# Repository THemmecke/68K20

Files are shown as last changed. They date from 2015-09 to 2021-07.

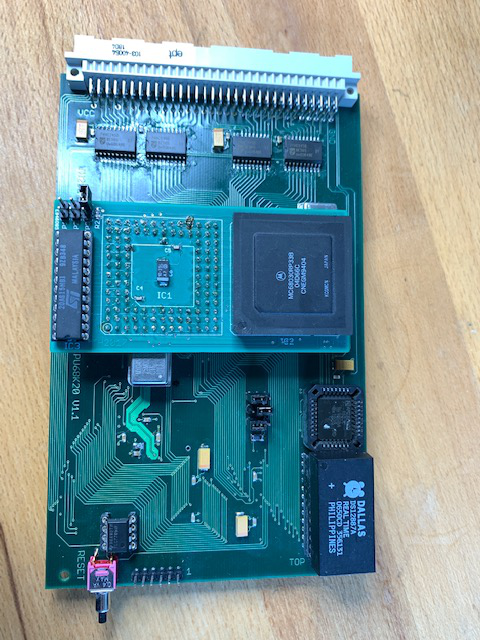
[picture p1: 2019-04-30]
ADAP030/IMG_0259.JPG

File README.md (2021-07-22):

# 68K20
68020 Board EAGLE/VHDL

This repository contains EAGLE and VHDL sources for a 68020 based SBC. The ECB based SBC provides a 68020 cpu, 68881/2 FPU, full 32 bit address and databus, 4MB SRAM and 512KB FLASH on board, 12(C)887 RTC.
It can be used with the GDP-FPGA (https://github.com/THemmecke/GDPFPGAII) to build a complete microcomputer system.

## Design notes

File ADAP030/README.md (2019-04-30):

# 68030 Adapter

With this adapter plugged into the 68020 socket of the CPU68K20 the card upgrades to an CPU68K30 with 

  - 68030/33Mhz CPU (tested)
  - MMU (!)
  - 68882 FPU

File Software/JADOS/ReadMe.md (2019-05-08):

# JADOS 3.50

This directory contains a zipped JADOS image for use with sd cards (GDP-FPGA) and the 680x0 SBCs.

block size: 512 byte
blocks:     133320
size:       68.259.840   Byte (65MB)

Copy to sd card with linux:

1) check with lsblk where your sd card is mounted:

```
$ lsblk 
NAME   MAJ:MIN RM  SIZE RO TYPE MOUNTPOINT
fd0      2:0    1    4K  0 disk 
sda      8:0    0  100G  0 disk 
|-sda1   8:1    0 92.4G  0 part /
|-sda2   8:2    0    1K  0 part 
`-sda5   8:5    0  7.6G  0 part 
sdc      8:32   1 14.1M  0 disk     <---- ()
`-sdc1   8:33   1 13.6M  0 part 
sr0     11:0    1 1024M  0 rom  
```

2) write image:

```
 [sudo] dd bs=512 count=133320 if=jados.img of=/dev/sdc [status=progress]
```

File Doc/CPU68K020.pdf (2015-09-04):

## CPU68K020

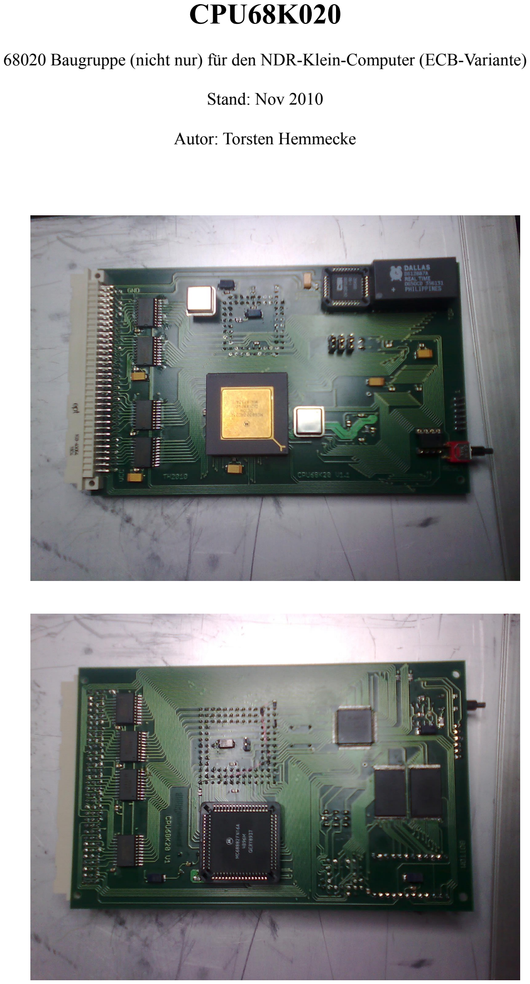
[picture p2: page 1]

68020 Baugruppe (nicht nur) für den NDR-Klein-Computer (ECB-Variante)

Stand: Nov 2010

Autor: Torsten Hemmecke

Wichtiger Hinweis:

Die in dieser Anleitung wiedergegebenen Schaltungen und Verfahren werden ohne Rücksicht auf die Patentlage oder Lizenzrechte Dritter mitgeteilt. Sie sind ausschließlich für private Zwecke und Lehrzwecke bestimmt und dürfen nicht gewerblich genutzt werden. *)
Alle Schaltungen und technische Angaben in dieser Anleitung wurden vom Autor sorgfältig erarbeitet bzw. zusammengestellt. Trotzdem sind Fehler nicht aus zuschließen. Daher kann der Autor weder eine Garantie noch die juristische Verantwortung oder irgend eine Haftung für Folgen, die auf fehlerhafte Angaben zurückgehen, übernehmen. Für die Mitteilung eventueller Fehler ist der Autor jederzeit dankbar.
Die Rechte an Firmennamen, Logos und Warenzeichen, die in dieser Anleitung genannt werden, liegen bei den jeweiligen Inhabern.

*) Bei gewerblicher Nutzung ist vorher die Genehmigung des möglichen Lizenz- oder Rechteinhabers einzuholen.

Inhalt

### 1 Vorwort

Die Baugruppe CPU68k020 entstand im Rahmen des Projektes „NKC Redesign“ das zum Ziel hat, den legendären NDR-Klein-Computer mit heute (Stand 2010) erhältlichen Bauelementen neu aufzubauen und bis hin zum Einsatz mit einem kleinen Linux-Kernel. Das ganze System verwendet einen ECB Bus, wobei die Belegung des Busses zum MC-Computer kompatibel ist und darüber hinaus 16/32bit Erweiterungen vorsieht.
Die CPU68k020 soll volle Software-Kompatibilität zum original NKC bieten.
Auf der Karte sind bis zu 4MB Speicher, ein 8bit-ROM für den BOOT-Loader / GP, eine Echtzeit-UHR (kompatibel zur Uhren-Baugruppe UHR3 von Jens Mewes), die komplette Banken-Logik und ein PLCC Sockel für eine FPU (MC68881/68882) integriert. Es steht ein 32-bit ECB-Bus-Interface zur Verfügung.

Zusammen mit der GDP-FPGA von Andreas Voggeneder steht damit ein vollständiges NKC System zur Verfügung, das bereits JADOS über eine SD-CARD bootet.

### 2 Änderungshistorie

In der vorliegenden Version 1.1.2 sind keine Fehler bekannt.

### 3 Kurzbeschreibung der Funktion

Die Baugruppe CPU68k020 stellt eine vollständige 32Bit CPU für den NKC dar. Sie enthält zusätzlich zur originalen CPU68020 bereits 4MB RAM, die komplette Banken-Logik sowie die UHR3 Baugruppe und ist voll softwarekompatibel zu diesen Baugruppen. Somit kann sämtliche Software des NKC darauf betrieben werden. Die Hardware ist auf einer Europakarte aufgebaut wird mit einen 32-Bit ECB-Bus-Anschluß betrieben werden.

### 4 Technische Daten

Europakarte 160 x 100 mm 4 Lagen (2 Supply Planes) CPU 68020-16/25/33 MHz
FPU 68881/68882
ECB-Bus (32-bit)
Stromaufnahme ca. …. mA
Gerätetyp; Betriebsspannung 5V 4GB adressierbar
4MB RAM OnBoard
512K FLASH OnBoard
RTC 12(C)887

### 5 Prinzipbeschreibung

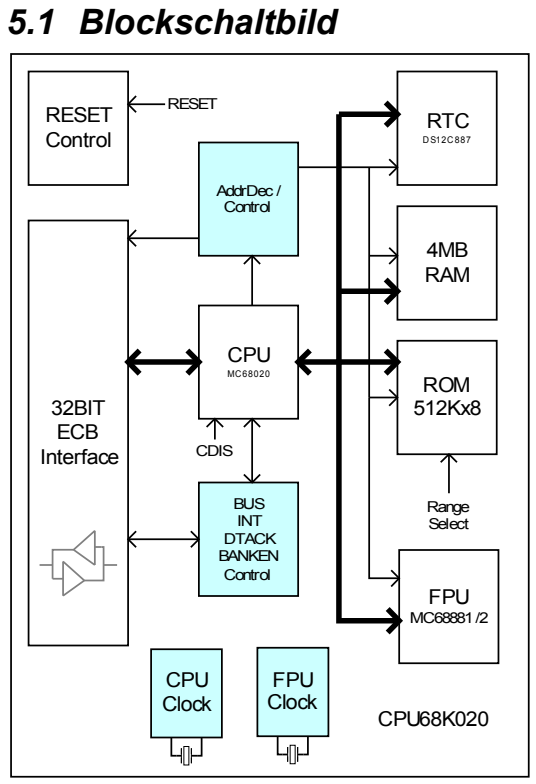
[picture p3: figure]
5.1 Blockschaltbild; AddrDec / Control; CPU Clock; 32BIT ECB Interface; CPU; RESET Control; RTC; 4MB RAM; ROM 512Kx8; BUS INT DTACK BANKEN Control; CPU68K020; FPU MC68881/2; Range Select; CDIS; FPU Clock; RESET

### 5.2 Beschreibung des Blockschaltbildes

Die Baugruppe stellt einen kompletten Signle Board Computer (SBC) mit 16Bit MC68020 CPU dar. Zusammen mit der GDP-FPGA entsteht so ein vollständiger NKC mit 68000 CPU.
Das Design ist dabei völlig offen und nicht auf den Betrieb im NKC beschränkt. Durch Anpassen des CPLDs kann die Funktionalität des SBC nach Belieben angepasst werden.

Es ist bereits eine RTC (Real Time Clock) mit einem DS12(C)887 von Dallas integriert, der im CPLD als UHR3 Baugruppe eingeblendet wird. Eine Funktionsbeschreibung findet sich in der Dokumentation von UHR3 [].

Es können bis zu 4MB RAM (NKC Vollausbau) und xK ROM eingesetzt werden. Die Verwendung der RAM/ROM Bereiche kann über die Konfiguration des CPLDs variiert werden. In der Grundkonfiguration werden 4MB RAM und xKB ROM als BOOT-Loader verwendet.

Die farblich hervorgehobenen Blöcke sind in einem CPLD realisiert.

Die Bus Steuerung sowie DTACK/WAIT Generierung wird im CPLD erledigt. Es können die IRQx, NMI und INT Leitungen des ECB Busses im CPLD beliebig auf die IPL Leitungen der CPU geschaltet werden.

Darüber hinaus kümmert sich das CPLD um die notwendigen Adress-Dekodierungen von IO und MEM Zugriffen (lokal/nicht lokal etc.) und realisiert das BANKEN Register zum Ausblenden des ROM aus dem Adressraum des 68020.

Als Reset Baustein wird ein TLC7725 eingesetzt. Der Baustein sorgt bei Einschalten für einen genügend langen RESET Puls, so dass sich die Versorgungsspannung und die Signale stabilisieren können. Außerdem wird die Versorgungsspannung überwacht und bei Unterschreitung ein Reset ausgelöst um einen undefinierten Zustand des Systems zu vermeiden Außerdem kann ein externer Reset-Taster angeschlossen werden.

Ein Sockel für eine FPU (68881 od. 68882) ist vorhanden und kann wahlweise bestückt werden.

Das 32Bit ECB Bus Interface stellt die Verbindung zu weiteren Karten über den ECB Bus her. So kann mit einer SRAM_24MB der verfügbare Speicher auf 28MB erweitert werden. Damit kann ohne Probleme ein uCLinux System betrieben werden. Der Zugriff auf die externe Speicherkarte (SRAM_24MB) ist mit einem 68020-25MHz getestet und benötigt keine weiteren WAIT-States.

### 5.3 Erweiterung des ECB-BUS auf 32 Bit

Damit der 68020 auch mit voller Bus-Breite auf Peripherie zugreifen kann, wurde der Bus auf 32-Bit erweitert. Er bleibt dabei Kompatibel zum Z80-Bus (siehe Baugruppe SBC4) und zum 16Bit Bus des 68000 (siehe Baugruppe CPU68K).

Reihe | A | B | C
1 | 5V | 5V | 5V
2 | D5 | A20 | D0
3 | D6 | A21 | D7
4 | D3 | A22 | D2
5 | D4 | A23 | A0
6 | A2 | D8 | A3
7 | A4 | D9 | A1
8 | A5 | D10 | A8
9 | A6 | D11 | A7
10 | WAIT\ | D12 | A24
11 | BUSRQ\ | D13 | A25
12 | A18 | D14 | A19
13 | | D15 | BANKEN
14 | A26 | D24 | D1
15 | (020-A0) | D25 | A27
16 | (020-A1) | D26 | A28
17 | A17 | IRQ4 | A11
18 | A14 | IRQ3 | A10
19 | A29 | IRQ2 | A16
20 | M1\ | IRQ1 | NMI\
21 | INT\ | IRQ0
22 | D27 | D16 | WR\
23 | D28 | D17
24 | D29 | D18 | RD\
25 | D30 | D19 | HALT/
26 | D31 | D20
27 | IORQ\ | D21 | A12
28 | | DS0/UDS/SIZ0 | A15
29 | A13 | DS1/LDS/SIZ1 | CLK
30 | A9 | D22 | MREQ\
31 | BUSAK\ | D23 | RESET\
32 | GND | GND | GND
GRÜN | = NKC-ECB-BUS Belegung
ORANGE | = 16Bit Erweiterung (68000)
VIOLETT | = 32Bit Erweiterung (68020 – asynchrones Bus Design)
HBLAU | = evtl. für synchrones Bus-Design (ab 68040) vorgesehen

### 5.4 Das CPLD

Im Folgenden wird im Wesentlichen das CPLD in der NKC Version beschrieben. Prinzipiell kann das Verhalten der CPU-Baugruppe auch an andere Anwendungsfälle angepasst werden, z.B. kann das Interrupthandling verfeinert und die BUS Arbitration für die Verwendung mehrerer CPUs angepasst werden. Auch die dekodierten Adressbereiche sind hier rekonfigurierbar.

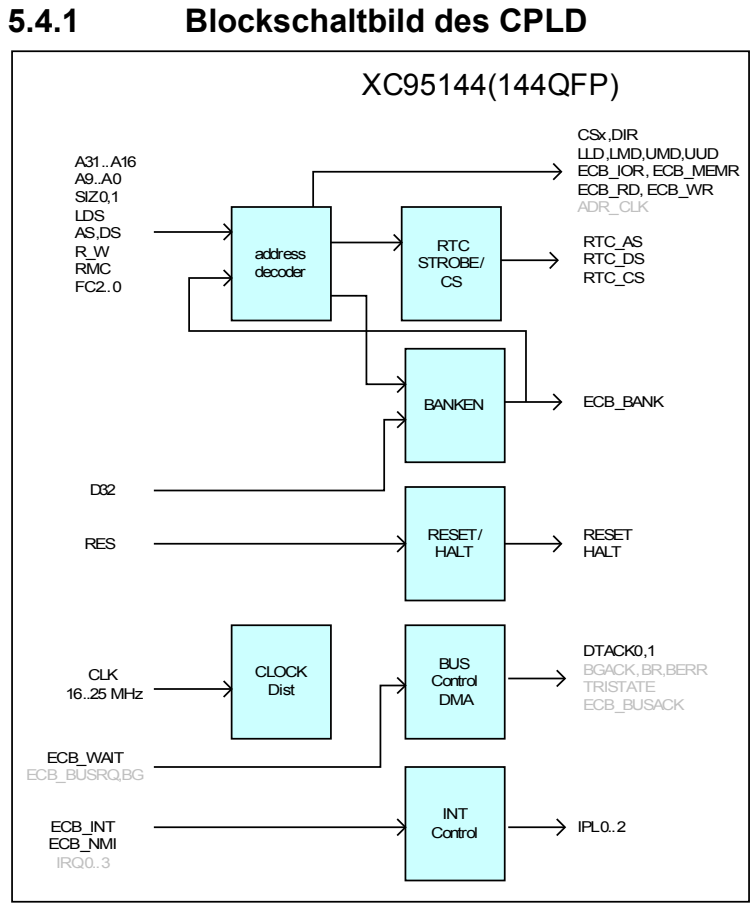
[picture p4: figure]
5.4.1 Blockschaltbild des CPLD; address decoder; RTC STROBE/; A31..A16 A9..A0 SIZ0,1 LDS AS,DS R_W RMC FC2..0; RTC_AS RTC_DS RTC_CS; XC95144(144QFP); CLK 16..25 MHz; BANKEN; ECB_BANK; RESET/ HALT; RESET HALT RES; CSx,DIR LLD,LMD,UMD,UUD ECB_IOR, ECB_MEMR ECB_RD, ECB_WR ADR_CLK; CLOCK Dist; BUS Control DMA; DTACK0,1 BGACK,BR,BERR TRISTATE ECB_BUSACK; INT; Control ECB_INT; IPL0..2; ECB_NMI IRQ0..3; ECB_WAIT ECB_BUSRQ,BG

Signale, die im Standard NKC Design nicht verwendet werden sind ausgegraut.

### 5.4.2 Funktionsbeschreibung des CPLDs

Das VHDL File definiert zunächst die Signale, die der Baustein nach Außen hin zur Verfügung stellt. Danach werden einige Konstanten definiert, die eine Anpassung/Änderung von Speicherbereichen und Register-Adressen erleichtern und das ganze Listing lesbarer machen.

Danach folgen einige Prozesse und ein wenig kombinatorische Logik:

Process STROBE:
Dient dem Erzeugen der für den Uhrenbaustein notwendigen Strobe Signale für Read und Write Zugriffe. Der Uhrenbaustein wird mit Motorola-Timing betrieben.

Process RESETPROC:
Dieser Prozess realisiert ein Tristate Gate, das beim Anliegen eines Reset Signals die Signale HALT und RESET des Prozessors auf NULL zieht. Die Verwendung als Tristate ist notwendig, da der Prozessor selbst diese Signale über Kommandos setzen kann.

Process BANKPROC
Realisiert das BANKEN Register.

Die Adress-Dekodierung wird über mehrere interne Signale generiert. Diese Art der Dekodierung gegenüber einer Switch-Anweisung oder If-then-else Verzweigung ist weniger fehleranfällig und besser lesbar.
Zunächst wird festgestellt, ob ein gültiger Speicherzugriff der CPU vorliegt und das Signal is_68k_mem_cycle gesetzt. Die Signale is_io_cs und is_mem_cs unterscheiden weiter zwischen IO und Speicher-Zugriff (dieses Konzept ist aus historischen Gründen für den NKC so realisiert, obgleich der 68000 keinen Unterschied zwischen IO und MEM Zugriff kennt).
Falls ein IO Zugriff vorliegt wird überprüft, ob es ein lokaler Zugriff auf das BANKEN-Register oder die RTC ist (rtc_data_cs, rtc_addr_cs, banken_cs) oder ob es sich um einen Zugriff auf eine externe IO-Karte handelt (ext_io_cs).
Bei MEM Zugriffen wird je nach den Jumper-Einstellungen (siehe ) und dem Zustand des BANKEN Registers das lokale RAM, ROM oder externer Speicher selektiert (ram_cs, rom_cs, ext_mem_cs). Bei lokalen Zugriffen werden die Chip-Select Signale entsprechend erzeugt, bei externen Zugriffen werden die Signale entsprechend auf den ECB BUS geschaltet.

Das BANKEN Register ist so realisiert wie im NKC. Es dient hier, anders als der Name vermuten lässt, nicht dem Banking sondern dem Ein- und Ausblenden des ROM Bausteins aus dem Speicherbereich des 68020. Der Namen BANKEN Register stammt aus der Verwendung als BANK-Umschalteregister im Z80 System.
Zu beachten ist, dass - anders als im original NKC - dieses Register hier auf 0xC9 gelegt wurde um nicht evtl. mit dem GP zu kollidieren. Das kann man bei Bedarf im CPLD ändern.
BANK | NC | NC | NC | NC | NC | NC | NC

0xC9 – BANK register

1 = BANK active
0 = BANK off

write

### 5.4.3 Programmierung des CPLDs

Zum Programmieren des CPLDs benötigt man das ISE-Webpack von Xilinx, dieses kann man (nach kostenloser Registrierung) von der Webseite www.xilinx.com herunterladen. Weiterhin benötigt man einen Programmieradapter, hierfür kann z.B. die Schaltung von www.holger-klabunde.de verwendet. Der Programmierstecker auf der GIDE Platine hat die Belegung dieses Programmers. Die CPLD-Daten sind in der Datei Xilinx.zip, diese entpackt man am besten nach c:\xilinx und nicht nach Eigene Dateien, da versch. Versionen des ISE-Webpacks nicht mit Leerzeichen in Verzeichnisnamen klar kommen. Zum Programmieren startet man den (Xilinx) Projekt Navigator und öffnet die Datei CPU68K20.ise, dort startet man unter Processes Implement Design -> Gererate Programming File – Configure Device (iMPACT), iMPACT das eigentliche Programmier Tool.

Bis zur Version 9.1.x ist ispIMPACT als Stand-Alone-Version vorhanden, das sich auch ohne ISE installieren lässt. Falls man also nur die fertigen JEDEC Files in’s CPLD brutzeln möchte, eine echte Alternative.

### 6 Beschreibung der Jumper

Im Folgenden werden die Einstellungsmöglichkeiten der Jumper beschrieben. Grundlage dabei ist das Default NKC-CPLD Design.

x bedeutet Jumper gesetzt
- bedeutet Jumper offen

### 6.1 EPROM-Offset

Der eingesetzte FLASH Baustein stellt max. 512K Speicher bereit. In der Grund-Konfiguration des CPLD werden davon nur 64K für den NKC Betrieb verwendet. Sollen für andere Anwendungen die ganzen 512K verwendet werden, muss das CPLD entsprechend angepasst werden. Über die Jumper J2,3,4 können verschiedene Bereiche innerhalb des FLASH Bausteines in die ersten 64K des NKC Speicherbereiches eingeblendet werden. Damit können mehrere GP Versionen oder eigene Programme gleichzeitig in einem FLASH Baustein gehalten werden.

J4 | J3 | J2 | EPROM-Offset
A18 A17 A16 | $0.0000
A18 A17 1 | $1.0000
A18 1 | A16 | $2.0000
A18 1 | 1 | $3.0000
1 | A17 A16 | $4.0000
1 | A17 1 | $5.0000
1 | 1 | A16 | $6.0000
1 | 1 | 1 | $7.0000

Beispiel:
Es sollen 2 GP Versionen über Jumper ausgewählt werden können. Dazu wird GP1 ab $00000 im EPROM abgelegt und GP2 ab $10000. Wenn alle Adresssignale an das EPROM geschaltet werden, bootet GP1. Wird J2 auf ‚1’ ge-jumpert, bootet dagegen GP2.

### 6.2 Cache-Disable

Wind JP100 (/CDIS) gesteckt ist der interne Befehls-Cache abgeschaltet (unabhängig vom Wert in CACR).

### 7 Aufbauanleitung

Schaltplan, Layout, Stückliste und Bestückungspläne sind im Anhang bzw. in den PCB-Daten zu finden.
Damit die Datenleitungen möglichst kurz werden, wurde die FPU auf die Unterseite der Platine platziert.

### 7.1 Umgang mit IC´s

CMOS-Bausteine sind hochempfindlich gegen elektrostatische Aufladung! Bewahren oder Transportieren Sie CMOS-Bausteine nur auf leitenden Schaumstoff! Alle Pins müssen kurzgeschlossen sein.
Achten Sie darauf, dass Sie Verbindung mit einer Erdungsmöglichkeit haben, bevor Sie mit diesen Bausteinen arbeiten. Geeignete ESD-Artikel gibt es im Fachhandel.

### 7.2 Aufbau Schritt für Schritt

Beim Layout der Platine wurde Wert auf eine möglichst hohe Nachbausicherheit gelegt. Dennoch war es notwendig TSSOP Bausteine zu verwenden, um die hohe Speicherdichte realisieren zu können. Daher muss ausdrücklich darauf hingewiesen werden, dass das Einlöten gerade bei diesen Bausteinen nur mit viel Erfahrung gelingen wird. Aufgrund der deutlich höheren Störsicherheit und der Anzahl integrierter Funktionen (UHR, Speicher etc.) ist ein 4-Lagen Design mit 0,2mm Strukturgröße notwendig geworden. Daher kann die Platine i.d.R. nicht vom Hobbyisten gefertigt werden.

Zunächst sollten die schwierigsten Bauteile eingelötet werden (IC1,11,15). Danach kommen die Treiber ICs und alle SMD Bauteile an die Reihe. Bevor der Sockel für den 68020 eingelötet wird darauf achten, dass der Jumper für CDIS und die anderen SMD Bauteile unter dem Sockel sauber eingelötet sind. Dann können der PGA Sockel und der PLCC Sockel (FPU) eingelötet werden. Danach werden alle IC Sockel, der VG Stecker eingelötet sowie alle Jumper und der Programmierstecker für das PLCC eingelötet.

Sind alle Sockel und fest einzulötenden Bauteile eingebaut, kann ein erster Test der Baugruppe erfolgen. Zunächst sollte geprüft werden, dass es keinen Kurzschluss zwischen 0 und 5V gibt (Ohmmeter). Dann 5V an die entsprechenden Klemmen des VG Steckers anlegen und überprüfen, ob irgendwelche Bauteile zu warm werden. Sollte dies der Fall sein, müssen die eingelöteten Bauteile überprüft werden (richtig herum eingelötet, korrekte Werte etc.).
Danach können alle gesockelten Bauteile aufgesteckt und der Test wiederholt werden.

Zuletzt muss noch das CPLD mit dem JEDEC File programmiert werden. Das kann entweder im System oder wieder durch Anschluss an eine 5V Stromversorgung geschehen.

### 8 Inbetriebnahme

### 8.1 Grundprogramme

8.1.1 68020 (32-Bit Grundprogramm)

Wenn das GP als bin File vorliegt kann es in das EPROM gebrannt werden.

Mit eingesetztem EPROM und Standard Einstellungen der Jumper sollte jetzt das GP Booten und das Menü des GP auf dem Bildschirm erscheinen.

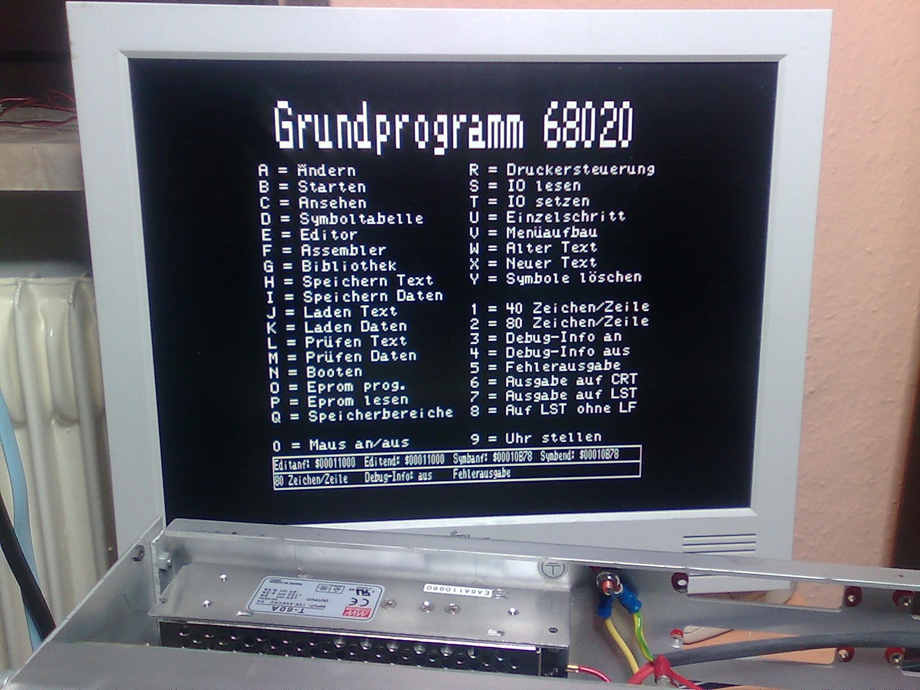
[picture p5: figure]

Im Bild ist das GP 6.3 abgebildet.

### 8.2 Betrieb mit CP/M-68K

Zum jetzigen Zeitpunkt (Stand Nov 2010) gibt es noch keine bootfähige Version für CPM/68K für den 6802

### 8.3 Betrieb mit Jados

Jados kann von GP aus über die Floppy (FLO-HD muss vorhanden sein) oder von der SD-CARD (ab GP Version 7.x ) gebootet werden. Eine Anpassung an den 68020 ist nicht notwendig. Nach dem Booten sollte die Eingabeaufforderung zu sehen sein:

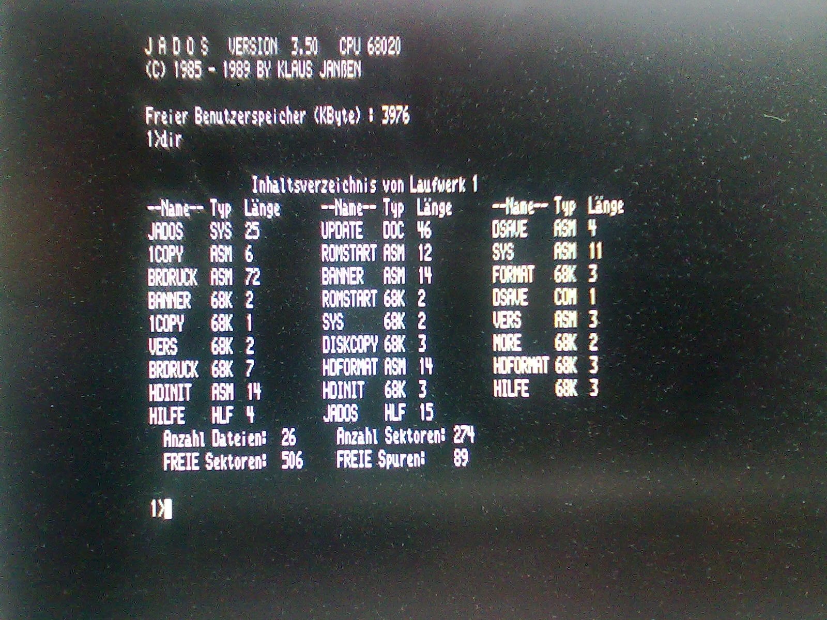
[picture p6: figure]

### 9 Fehlerkorrekturen

In der vorliegenden Version 1.1.2 sind bisher nur ein Problem bekannt:

Bei Betrieb des 68020 mit mehr als 16MHz läuft die FLOHD Baugruppe nicht sauber, es gibt da noch ein Timingproblem. Allerdings ist noch nicht ganz klar, ob das an der CPU oder der FLOHD Karte liegt.

Beim Aufbau sollte die Adresse des Banken-Registers im eingesetzten CPLD und der Software überprüft werden.
Da dieses Register im Grunde nur dazu verwendet wird, beim Boot-Vorgang das GP in den hohen Speicherbereich zu laden und dann das ROM auszublenden, wurde es auf 0xC9 gesetzt um mit Funktionen im GP nicht in Konflikt zu geraten

### 10 Quellenhinweise

M68020 User’s Manual MOTOROLA | 1992
M68020 Addendum FREESCALE | 2003
CPU68020 / Graf Elektronik | Ausgabe 3
UHR3 Jens Mewes 2007

DS12C887 RTC Datasheet | DALLAS 020900
Die Bank Boot Baugruppe / GES
BOOTRAM68k Gerald Ebert 2007
Handbuch Grundprogramm V 7.0 Jens Mewes 2007
Handbuch Jados 3.50 Klaus Janßen 1985-1990

http://www.schuetz.thtec.org/index.htmlhttp://www.drcrazy.de/nkc

### 11 Anhänge

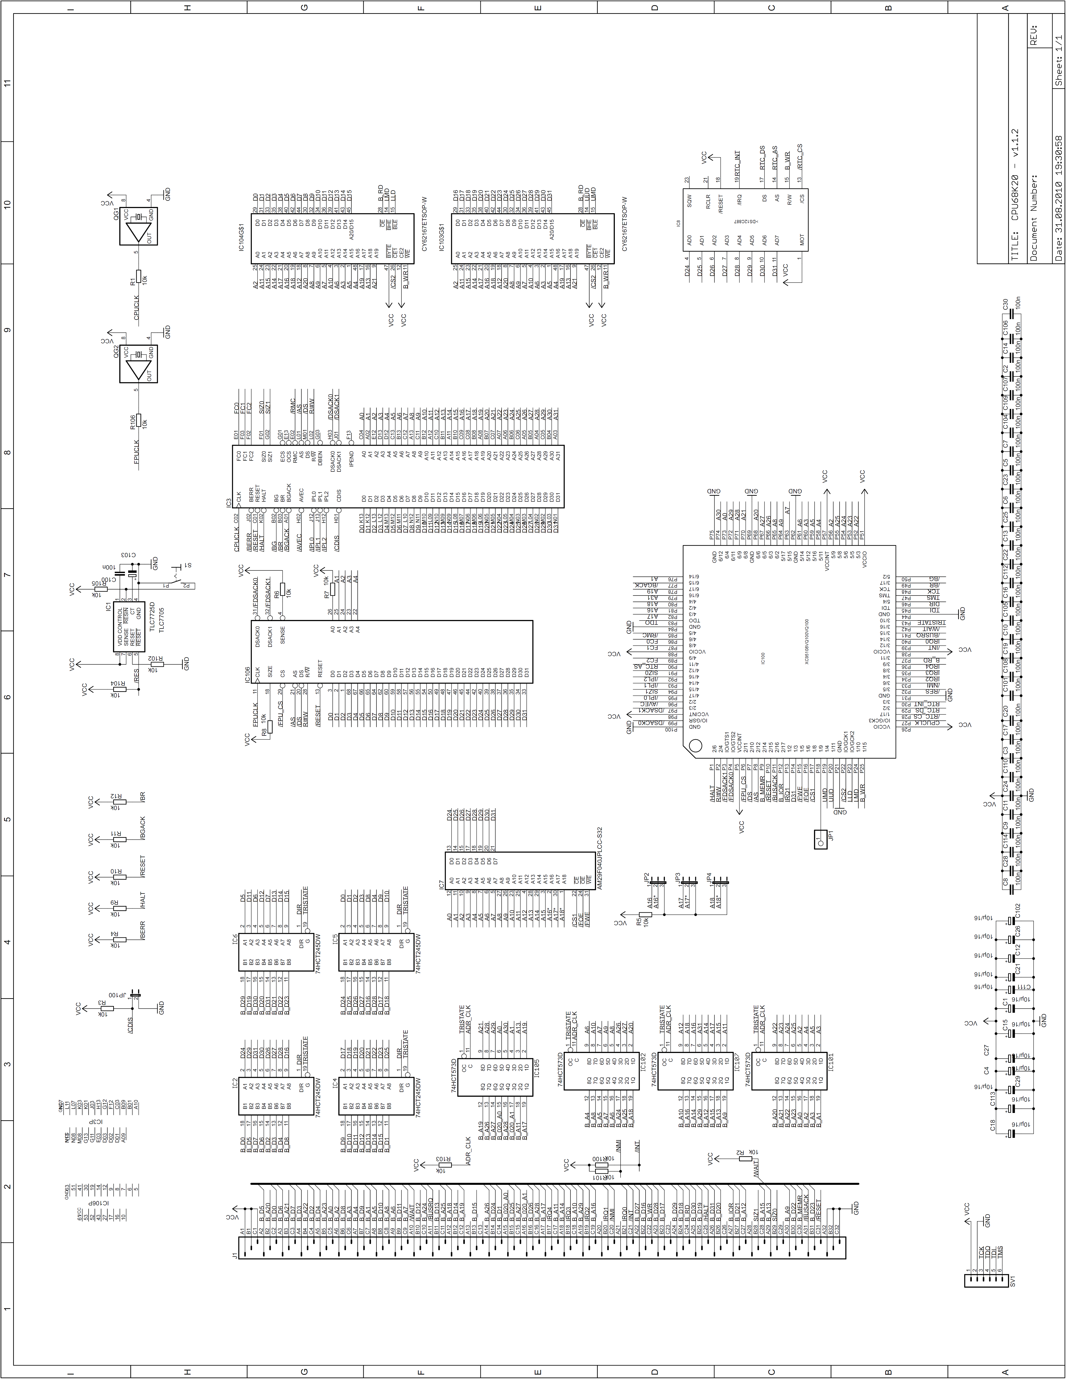
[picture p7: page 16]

### 11.1 Schaltplan

### 11.2 Stückliste

Menge Wert | Device | Bauteile
3 | | JP2E | JP2, JP3, JP4
1 | | MA06-1 | SV1
1 | | MC68020RC | IC3
1 | | MC68881FN-SOC | IC106
1 | | PINHD-1X1 | JP1
2 | | QG5460 | QG1, QG2
1 | | TS-21A | S1
1 | | VG96P | J1
13 | 10µ/16 | CPOL-EUSMCC | C1, C4, C12, C15, C18, C21, C26, C27, C29,
| | | C102, C103, C111, C113
17 | 10k | R-EU_M0805 | R1, R2, R3, R4, R6, R7, R8, R9, R10, R11,
| | | R12, R100, R101, R102, R103, R104, R106
2 | 10k | R-EU_M1206 | R5, R105
4 | 74HCT245DW | 74HCT245DW | IC2, IC4, IC5, IC6
4 | 74HCT573D | 74HCT573D | IC101, IC102, IC105, IC107
32 | 100n | C-EUC0603K | C2, C3, C5, C6, C7, C8, C9, C10, C11, C13, C14, C16, C17, C19, C20, C22, C23, C24, C25, C28, C30, C100, C101, C104, C105, C106, C107, C108, C109,
| | | C110, C112, C114
1 | AM29F040JPLCC-S32 AM29F040JPLCC-S32 IC7
1 | CDIS | JP1E | JP100
2 | CY62167ETSOP-W | CY62167ETSOP-W | IC103, IC104
1 | DS12C887DIL24 | DS12C887DIL24 | IC8
1 | TLC7725D | TLC7725D | IC1
1 | XC95108VQ100VQ100 XC95108VQ100VQ100 IC100

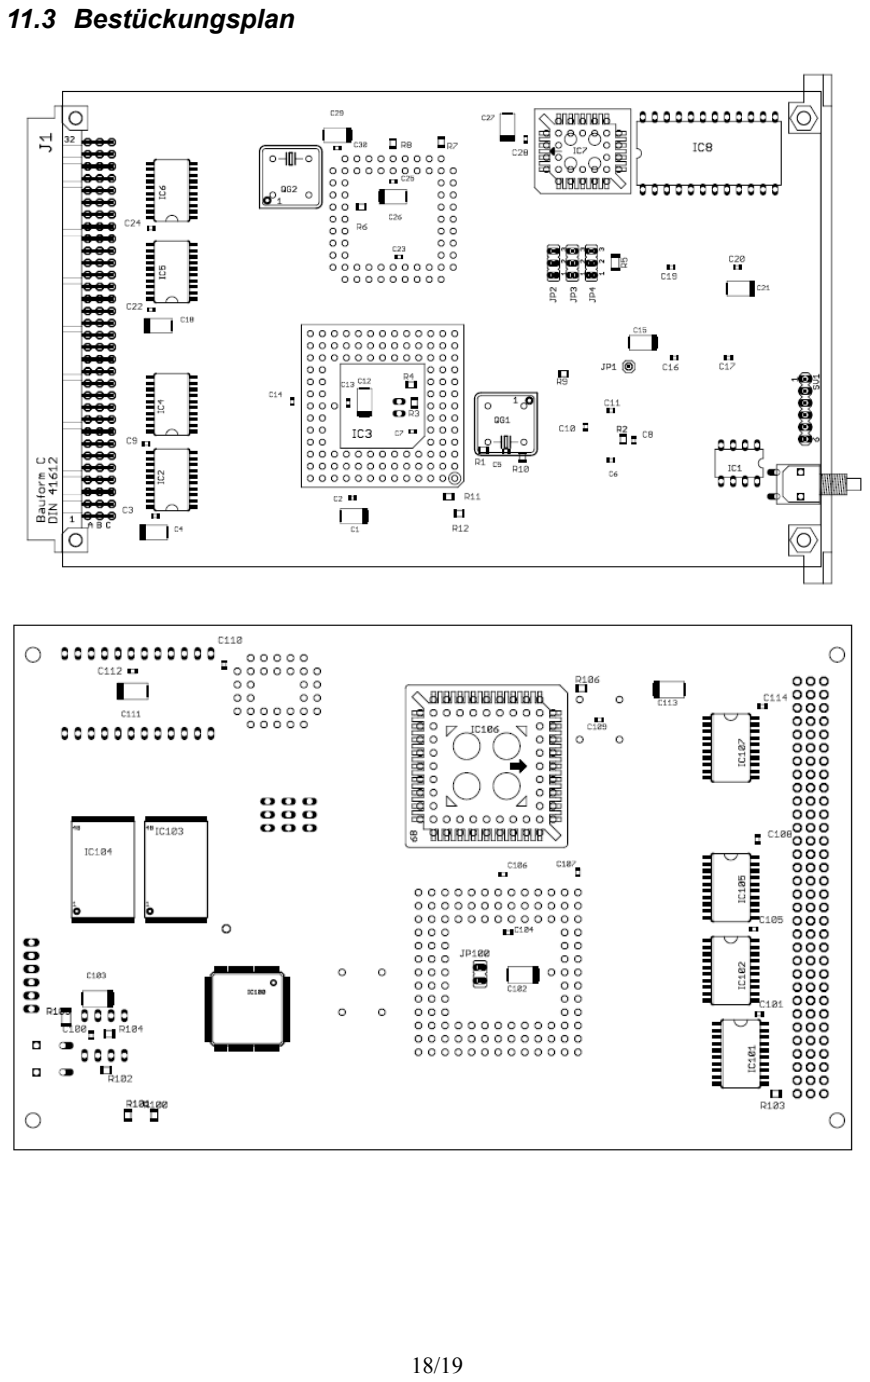
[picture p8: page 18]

### 11.3 Bestückungsplan

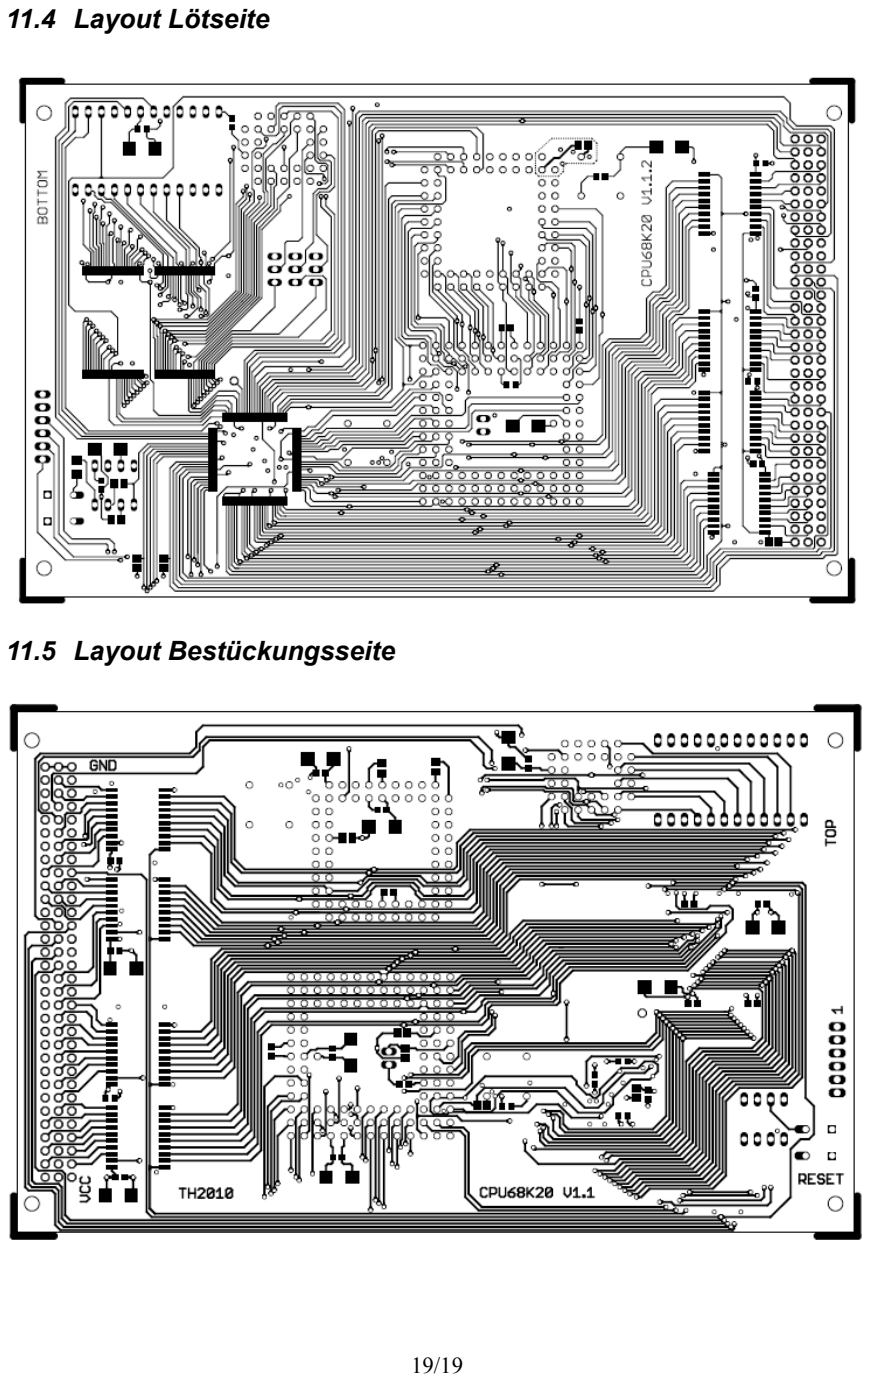
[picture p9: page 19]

### 11.4 Layout Lötseite

### 11.5 Layout Bestückungsseite

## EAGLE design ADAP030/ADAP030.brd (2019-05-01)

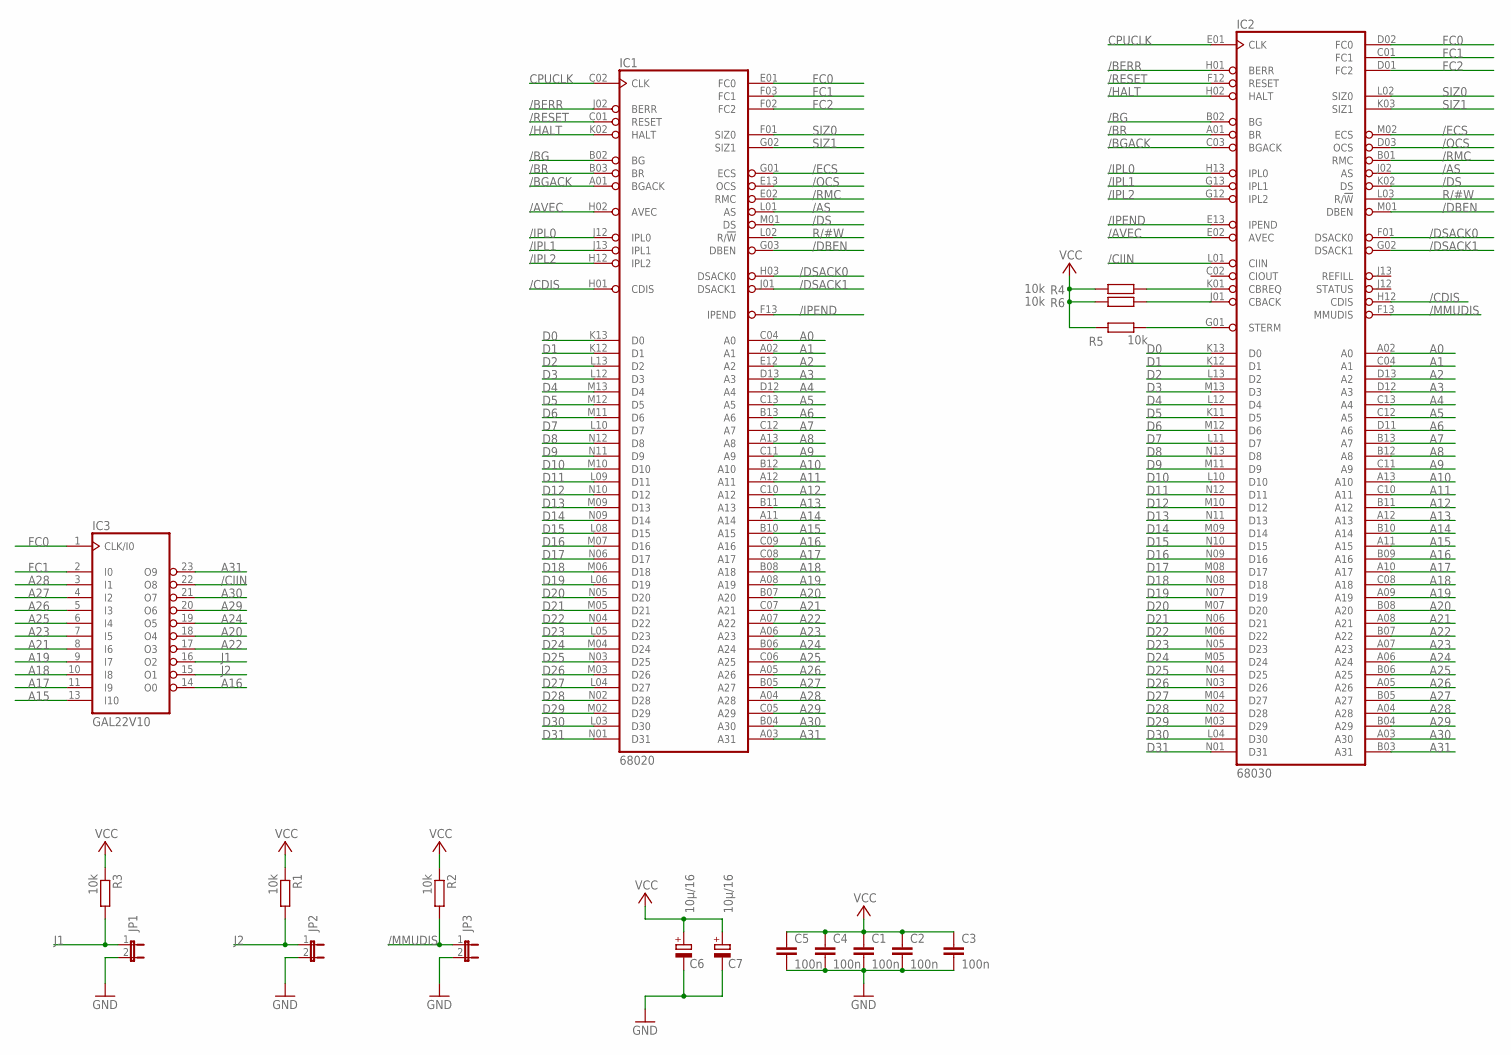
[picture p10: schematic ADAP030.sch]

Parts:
C1, C2, C3, C4, C5: 100n; C0603K
C6, C7: 10µ/16; SMC_C
IC1: 68020; MPGA114
IC2: 68030; MPGA128
IC3: GAL22V10; DIL24-3
JP1, JP2, JP3: JP1E; JP1
R1, R2, R3, R4, R5, R6: 10k; M0805

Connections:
/AS: IC1.L01 (AS), IC2.J02 (AS)
/AVEC: IC1.H02 (AVEC), IC2.E02 (AVEC)
/BERR: IC1.J02 (BERR), IC2.H01 (BERR)
/BG: IC1.B02 (BG), IC2.B02 (BG)
/BGACK: IC1.A01 (BGACK), IC2.C03 (BGACK)
/BR: IC1.B03 (BR), IC2.A01 (BR)
/CDIS: IC1.H01 (CDIS), IC2.H12 (CDIS)
/CIIN: IC2.L01 (CIIN), IC3.22 (O8)
/DBEN: IC1.G03 (DBEN), IC2.M01 (DBEN)
/DS: IC1.M01 (DS), IC2.K02 (DS)
/DSACK0: IC1.H03 (DSACK0), IC2.F01 (DSACK0)
/DSACK1: IC1.J01 (DSACK1), IC2.G02 (DSACK1)
/ECS: IC1.G01 (ECS), IC2.M02 (ECS)
/HALT: IC1.K02 (HALT), IC2.H02 (HALT)
/IPEND: IC1.F13 (IPEND), IC2.E13 (IPEND)
/IPL0: IC1.J12 (IPL0), IC2.H13 (IPL0)
/IPL1: IC1.J13 (IPL1), IC2.G13 (IPL1)
/IPL2: IC1.H12 (IPL2), IC2.G12 (IPL2)
/MMUDIS: IC2.F13 (MMUDIS), JP3.1, R2.2
/OCS: IC1.E13 (OCS), IC2.D03 (OCS)
/RESET: IC1.C01 (RESET), IC2.F12 (RESET)
/RMC: IC1.E02 (RMC), IC2.B01 (RMC)
A0: IC1.C04 (A0), IC2.A02 (A0)
A1: IC1.A02 (A1), IC2.C04 (A1)
A2: IC1.E12 (A2), IC2.D13 (A2)
A3: IC1.D13 (A3), IC2.D12 (A3)
A4: IC1.D12 (A4), IC2.C13 (A4)
A5: IC1.C13 (A5), IC2.C12 (A5)
A6: IC1.B13 (A6), IC2.D11 (A6)
A7: IC1.C12 (A7), IC2.B13 (A7)
A8: IC1.A13 (A8), IC2.B12 (A8)
A9: IC1.C11 (A9), IC2.C11 (A9)
A10: IC1.B12 (A10), IC2.A13 (A10)
A11: IC1.A12 (A11), IC2.C10 (A11)
A12: IC1.C10 (A12), IC2.B11 (A12)
A13: IC1.B11 (A13), IC2.A12 (A13)
A14: IC1.A11 (A14), IC2.B10 (A14)
A15: IC1.B10 (A15), IC2.A11 (A15), IC3.13 (I10)
A16: IC1.C09 (A16), IC2.B09 (A16), IC3.14 (O0)
A17: IC1.C08 (A17), IC2.A10 (A17), IC3.11 (I9)
A18: IC1.B08 (A18), IC2.C08 (A18), IC3.10 (I8)
A19: IC1.A08 (A19), IC2.A09 (A19), IC3.9 (I7)
A20: IC1.B07 (A20), IC2.B08 (A20), IC3.18 (O4)
A21: IC1.C07 (A21), IC2.A08 (A21), IC3.8 (I6)
A22: IC1.A07 (A22), IC2.B07 (A22), IC3.17 (O3)
A23: IC1.A06 (A23), IC2.A07 (A23), IC3.7 (I5)
A24: IC1.B06 (A24), IC2.A06 (A24), IC3.19 (O5)
A25: IC1.C06 (A25), IC2.B06 (A25), IC3.6 (I4)
A26: IC1.A05 (A26), IC2.A05 (A26), IC3.5 (I3)
A27: IC1.B05 (A27), IC2.B05 (A27), IC3.4 (I2)
A28: IC1.A04 (A28), IC2.A04 (A28), IC3.3 (I1)
A29: IC1.C05 (A29), IC2.B04 (A29), IC3.20 (O6)
A30: IC1.B04 (A30), IC2.A03 (A30), IC3.21 (O7)
A31: IC1.A03 (A31), IC2.B03 (A31), IC3.23 (O9)
CBACK: IC2.J01 (CBACK), R6.2
CNREQ: IC2.K01 (CBREQ), R4.2
CPUCLK: IC1.C02 (CLK), IC2.E01 (CLK)
D0: IC1.K13 (D0), IC2.K13 (D0)
D1: IC1.K12 (D1), IC2.K12 (D1)
D2: IC1.L13 (D2), IC2.L13 (D2)
D3: IC1.L12 (D3), IC2.M13 (D3)
D4: IC1.M13 (D4), IC2.L12 (D4)
D5: IC1.M12 (D5), IC2.K11 (D5)
D6: IC1.M11 (D6), IC2.M12 (D6)
D7: IC1.L10 (D7), IC2.L11 (D7)
D8: IC1.N12 (D8), IC2.N13 (D8)
D9: IC1.N11 (D9), IC2.M11 (D9)
D10: IC1.M10 (D10), IC2.L10 (D10)
D11: IC1.L09 (D11), IC2.N12 (D11)
D12: IC1.N10 (D12), IC2.M10 (D12)
D13: IC1.M09 (D13), IC2.N11 (D13)
D14: IC1.N09 (D14), IC2.M09 (D14)
D15: IC1.L08 (D15), IC2.N10 (D15)
D16: IC1.M07 (D16), IC2.N09 (D16)
D17: IC1.N06 (D17), IC2.M08 (D17)
D18: IC1.M06 (D18), IC2.N08 (D18)
D19: IC1.L06 (D19), IC2.N07 (D19)
D20: IC1.N05 (D20), IC2.M07 (D20)
D21: IC1.M05 (D21), IC2.N06 (D21)
D22: IC1.N04 (D22), IC2.M06 (D22)
D23: IC1.L05 (D23), IC2.N05 (D23)
D24: IC1.M04 (D24), IC2.M05 (D24)
D25: IC1.N03 (D25), IC2.N04 (D25)
D26: IC1.M03 (D26), IC2.N03 (D26)
D27: IC1.L04 (D27), IC2.M04 (D27)
D28: IC1.N02 (D28), IC2.N02 (D28)
D29: IC1.M02 (D29), IC2.M03 (D29)
D30: IC1.L03 (D30), IC2.L04 (D30)
D31: IC1.N01 (D31), IC2.N01 (D31)
FC0: IC1.E01 (FC0), IC2.D02 (FC0), IC3.1 (CLK/I0)
FC1: IC1.F03 (FC1), IC2.C01 (FC1), IC3.2 (I0)
FC2: IC1.F02 (FC2), IC2.D01 (FC2)
GND: C1.2, C2.2, C3.2, C4.2, C5.2, C6.-, C7.-, IC1.A10 (GND), IC1.B01 (GND), IC1.B09 (GND), IC1.C03 (GND), IC1.F12 (GND), IC1.G12 (GND), IC1.H13 (GND), IC1.J03 (GND), IC1.K01 (GND), IC1.K03 (GND), IC1.L07 (GND), IC1.L11 (GND), IC1.N07 (GND), IC2.C05 (GND), IC2.C07 (GND), IC2.C09 (GND), IC2.E03 (GND), IC2.E11 (GND), IC2.F03 (GND), IC2.G03 (GND), IC2.G11 (GND), IC2.J03 (GND), IC2.J11 (GND), IC2.L05 (GND), IC2.L07 (GND), IC2.L08 (GND), IC2.L09 (GND), IC3.12 (GND), JP1.2, JP2.2, JP3.2
J1: IC3.16 (O2), JP1.1, R3.2
J2: IC3.15 (O1), JP2.1, R1.2
R/#W: IC1.L02 (R/!W), IC2.L03 (R/!W)
SIZ0: IC1.F01 (SIZ0), IC2.L02 (SIZ0)
SIZ1: IC1.G02 (SIZ1), IC2.K03 (SIZ1)
STERM: IC2.G01 (STERM), R5.2
VCC: C1.1, C2.1, C3.1, C4.1, C5.1, C6.+, C7.+, IC1.A09 (VCC), IC1.D01 (VCC), IC1.D02 (VCC), IC1.D03 (VCC), IC1.E03 (VCC), IC1.G11 (VCC), IC1.G13 (VCC), IC1.M08 (VCC), IC1.N08 (VCC), IC1.N13 (VCC), IC2.C06 (VCC), IC2.D04 (VCC), IC2.D10 (VCC), IC2.F02 (VCC), IC2.F11 (VCC), IC2.H03 (VCC), IC2.H11 (VCC), IC2.K04 (VCC), IC2.K10 (VCC), IC2.L06 (VCC), IC3.24 (VCC), R1.1, R2.1, R3.1, R4.1, R5.1, R6.1

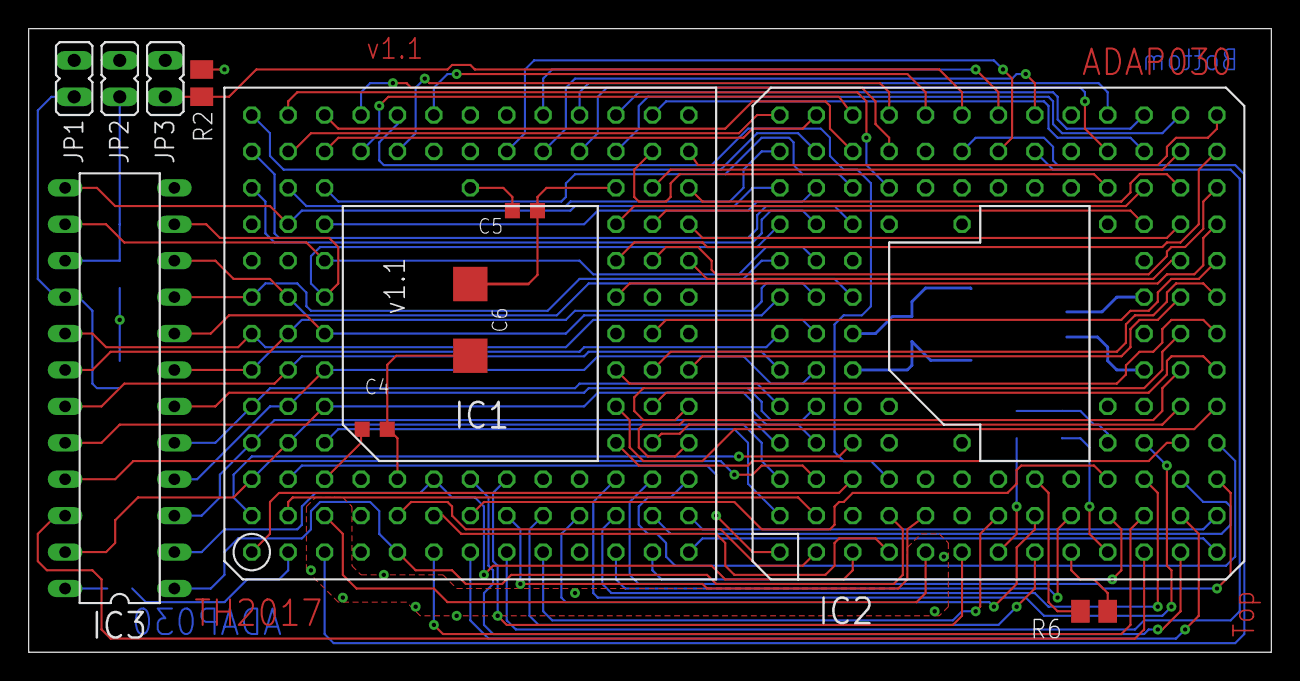
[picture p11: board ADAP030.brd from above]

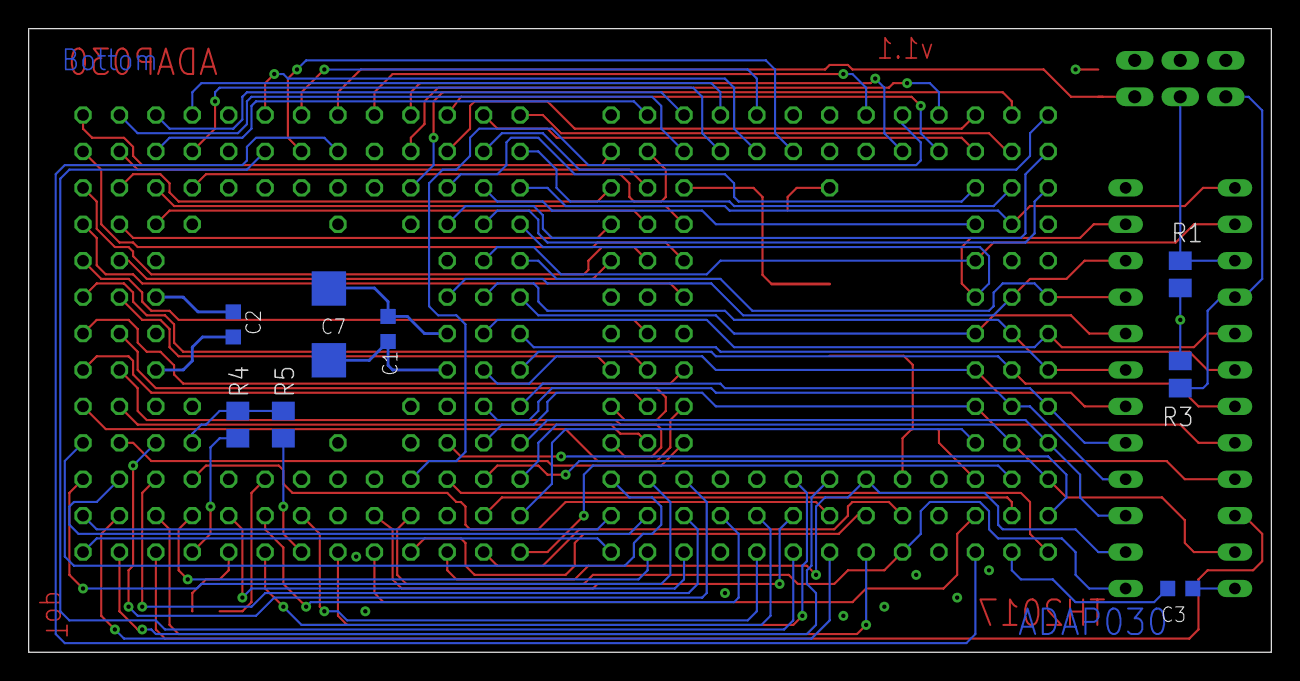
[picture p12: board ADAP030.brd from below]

Board: 4 copper layers, 86.7 x 43.5 mm, 19 parts (8 on the bottom side), 100 nets.

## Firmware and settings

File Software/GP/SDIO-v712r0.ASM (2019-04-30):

*******************************************************************************
*                          680xx Grundprogramm sdio                           *
*                             2016 Jens Mewes                                 *
*                               V 7.12 Rev 0                                  *
*                                01.01.2016                                   *
*                             SD-Card-Routinen                                *
*******************************************************************************


sdtest:                         * Test, ob Laufwerk vorhanden
                                        * d4 enthält Laufwerk
 movem.l d1-d7/a1-a4/a6, -(a7)
 link a3, #-24
 btst.b #6, keydil(a5)                  * GDP-FPGA da?
 beq.s sdtst00                          * nein, dann Softwarelösung
 bra sd1test
sdtst00:
 and #$0f, d4
 cmp.b #1, d4                           * Card 0?
 bne.s sdtst01                          * nein
 move.b #SPI_CS0, d5                    * d5 = SPI_CS
 lea sd1geo(a5), a6                     * Speicher für Grösse...
 bra.s sdtst02
sdtst01:
 cmp.b #2, d4                           * Card 1?
 bne sdxtster                           * nein, dann Fehler
 move.b #SPI_CS1, d5
 lea sd2geo(a5), a6
sdtst02:
 move.b #$ff, d2                        * d2 = sdout
 move.b #SPI_DI, d4                     * d4 = SPI_DI
 move.b #SPI_DO, d6                     * d6 = SPI_DO
 move.b #SPI_CLK, d7                    * d7 = SPI_CLK
 
 lea sdrdbyte(pc), a4
 move.l a4, SD_RDBYTE(a3)
 lea sdwrbyte(pc), a4
 move.l a4, SD_WRBYTE(a3)
 lea sdcsakt(pc), a4
 move.l a4, SD_CSAKT(a3)
 lea sdcsnakt(pc), a4
 move.l a4, SD_CSNAKT(a3)
 bra.s sdxtst

sd1test:
 and #$0f, d4
 cmp.b #1, d4                           * Card 0?
 bne.s sd1tst01                         * nein
 move.b #SPIH0_CS, d5                   * d5 = SPI_CS
 lea sd1geo(a5), a6                     * Speicher für Grösse...
 bra.s sd1tst02
sd1tst01:
 cmp.b #2, d4                           * Card 1?
 bne sdxtster                           * nein, dann Fehler
 move.b #SPIH1_CS, d5
 lea sd2geo(a5), a6
sd1tst02:
 move.b #$81, d2                        * d2 = sdout 10MHz
 lea sd1rdbyte(pc), a4
 move.l a4, SD_RDBYTE(a3)
 lea sd1wrbyte(pc), a4
 move.l a4, SD_WRBYTE(a3)
 lea sd1csakt(pc), a4
 move.l a4, SD_CSAKT(a3)
 lea sd1csnakt(pc), a4
 move.l a4, SD_CSNAKT(a3)

sdxtst:
 movea.l a6, a1                         * Adresse der Ausgabedaten sichern
 bsr sdinit
 tst.b d0
 bmi sdxtster                           * Fehler SD-Card nicht gefunden
 lea idebuff(a5), a0
 lea spcmd9(pc), a2                     * CSD Kommando
 move #16, d0                           * 16 Byte
 bsr sdrdblk                            * CSD-Register lesen
 lea idebuff(a5), a0
 tst SDART(a6)
 beq.s sdxtst02                         * MMC- oder SDv1-Card
 cmp #3, SDART(a6)
 bne.s sdxtst01
 lea sdhctxt(pc), a2
 bsr sdhcsize                           * SDHC-Card
 bra.s sdxtst05
sdxtst01:
 lea sd2txt(pc), a2
 bsr sdcsize                            * SDv2-Card
 bra.s sdxtst05
sdxtst02:
 move.b 0(a0), d0                       * CSD Struct
 btst.b #7, d0                          * MMC-Card?
 beq.s sdxtst03                         * Ja
 move #1, SDART(a6)                     * sonst SDv1-Card
 lea sdtxt(pc), a2
 bra.s sdxtst04
sdxtst03:
 lea mmctxt(pc), a2
sdxtst04:
 bsr sdcsize
sdxtst05:
 addq.l #SDNAME, a6                     * a6 auf SD-Name
sdxtst06:
 move.b (a2)+, (a6)+
 bne.s sdxtst06
 subq.l #1, a6                          * auf die Null
 cmp #512, d0                           * noch von sdcXXsize
 bne.s sdxtster                         * nicht unterstützte Blockgrösse
 clr.l d0
 lea spcmd10(pc), a2                    * CID Kommando
 move #16, d0                           * 16 Byte
 bsr sdrdblk                            * CID Bytes einlesen
 lea idebuff(a5), a0                    * Puffer zurück
 addq.l #3, a0                          * a0 auch auf Name
 moveq #5-1, d3                         * 5 Bytes
sdxtst07:
 move.b (a0)+, (a6)+
 dbra d3, sdxtst07
 clr.b (a6)+                            * zum Schluß ne Null
 movea.l a1, a0                         * Ausgabepuffer in a0
 clr.l d0                               * Alles OK
 unlk a3
 movem.l (a7)+, d1-d7/a1-a4/a6
 bra carres
sdxtster:
 moveq #-1, d0
 unlk a3
 movem.l (a7)+, d1-d7/a1-a4/a6
 bra carset


sdcsize:
 move.b 6(a0), d0                       * MSB von C_SIZE
 and.b #$03, d0                         * nur Bit 0 und 1
 lsl.l #8, d0                           * 8 Bit nach Links
 move.b 7(a0), d0                       * die nächsten 8 Bit
 lsl.l #8, d0                           * erstmal 8 Bit weiter
 move.b 8(a0), d0                       * hier kommt der Rest
 lsr.l #6, d0                           * wieder 6 Bit zurück
 addq.l #1, d0                          * um 1 erhöhen
 move.l d0, d1                          * C_SIZE nach d1 sichern
 clr.l d0
 move.b 9(a0), d0                       * die beiden MSBs von C_SIZE_MULT
 lsl.w #8, d0                           * jetzt im oberen Byte
 move.b 10(a0), d0                      * das letzte Bit
 lsr.w #7, d0                           * auf Bit 2-0
 and.w #$7, d0                          * nur 3 Bit
 addq.l #2, d0                          * Jetzt korrekter Wert
 asl.l d0, d1                           * (C_SIZE+1)*2^(C_SIZE_MULT+2)
 clr.l d0
 move.b 5(a0), d0                       * READ_BLK_LEN
 and.b #$0f, d0                         * nur unteren 4 Bit
 asl.l d0, d1                   * (C_SIZE+1)*2^(C_SIZE_MULT+2)*2^READ_BLK_LEN
 lsr.l #8, d1
 lsr.l #1, d1                           * /512 => in Sektoren
 move.l d1, SDSIZE(a6)                  * Grösse (in Sektoren) abspeichern
 moveq.l #1, d1
 asl.l d0, d1
 move d1, d0
 move.w d0, SDBPBLK(a6)                 * Bytes pro Block abspeichern
 rts


sdhcsize:
 clr.l d1
 move.b 7(a0), d1                       * MSB
 and.b #$3f, d1                         * obere Bytes nicht
 swap d1                                * jetzt in Byte #16 - #21
 move.b 8(a0), d1
 lsl #8, d1                             * nach Byte #15 - #8
 move.b 9(a0), d1                       * jetzt auch LSB
 move #10, d0
 lsl.l d0, d1                           * *1024 => in Sektoren
 move.l d1, SDSIZE(a6)
 move #512, d0
 move.w d0, SDBPBLK(a6)                 * Bytes pro Block abspeichern
 rts
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
